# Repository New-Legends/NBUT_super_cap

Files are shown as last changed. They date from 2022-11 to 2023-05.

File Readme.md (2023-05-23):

Image text
# 这是一份由NEW LEGENDS战队开发的10节50法拉电容引爆代码

##  接口介绍:
###      I2C接口
          I2C1: PB7->SDA PB6->SCL             
                连接超级电容充电模块用于检测充电功率
          I2C2: PB11->SDA PB10->SCL
                连接电池用于电池功率检测

###      LED灯接口
          白灯: PB5 输出PWN充电指示灯 pwn
          蓝灯: PA3 超电初始化完成后常亮 闪烁代表初始化失败 ready
          绿灯: PA4 超电放电时绿灯常亮 run
          橙灯: PA5 超电电压大于20v full
          红灯: PA6 电容电压小于12V low

###     充电模块LM5106
          使能: PB3 高电平开启充电 低电平关闭充电
          PWM控制:  PB4控制占空比控制充电电压

###     CAN通讯模块
          CAN_TX -> PB9  CAN_RX -> PB8
          控制板的CAN ID为固定的0x401,此ID固定不出现严重冲突不改！！！
          2023/5/20在这个爱的日子，加入一个新的通讯ID，0x402用于传输功率数据
## 充电接口介绍
            充电使用PWM的占空比控制，占空比越高，则充电功率越大

## 相关数据介绍
            cap_data 用于储存通过can通讯的底盘控制板数据
            cap_ctrl_data 用于储存控制变量

# 
      V1.1 发现问题，控制策略存在问题，尝试与底盘控制板协同控制
            默认升压模块开启，当电容没电时强行降速，直至不超功率运行
            使用该超电板需要将底盘电机的电调的电阻关闭

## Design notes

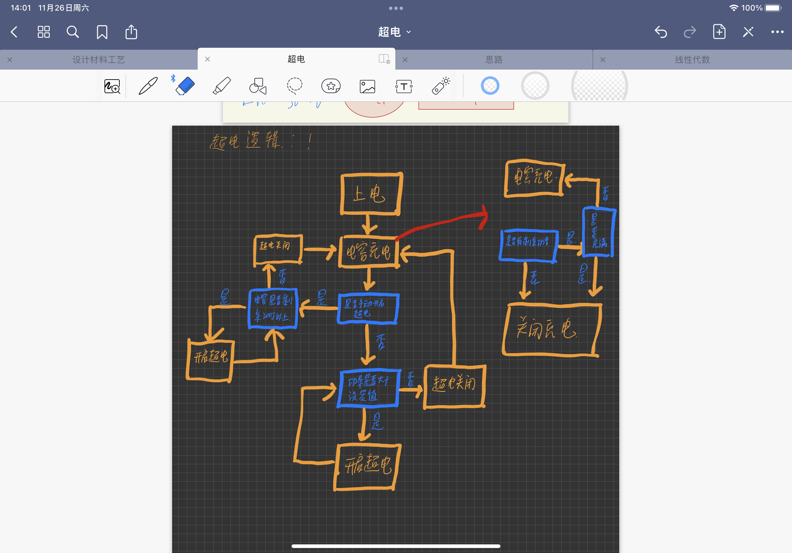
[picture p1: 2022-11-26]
超电运行逻辑图.png

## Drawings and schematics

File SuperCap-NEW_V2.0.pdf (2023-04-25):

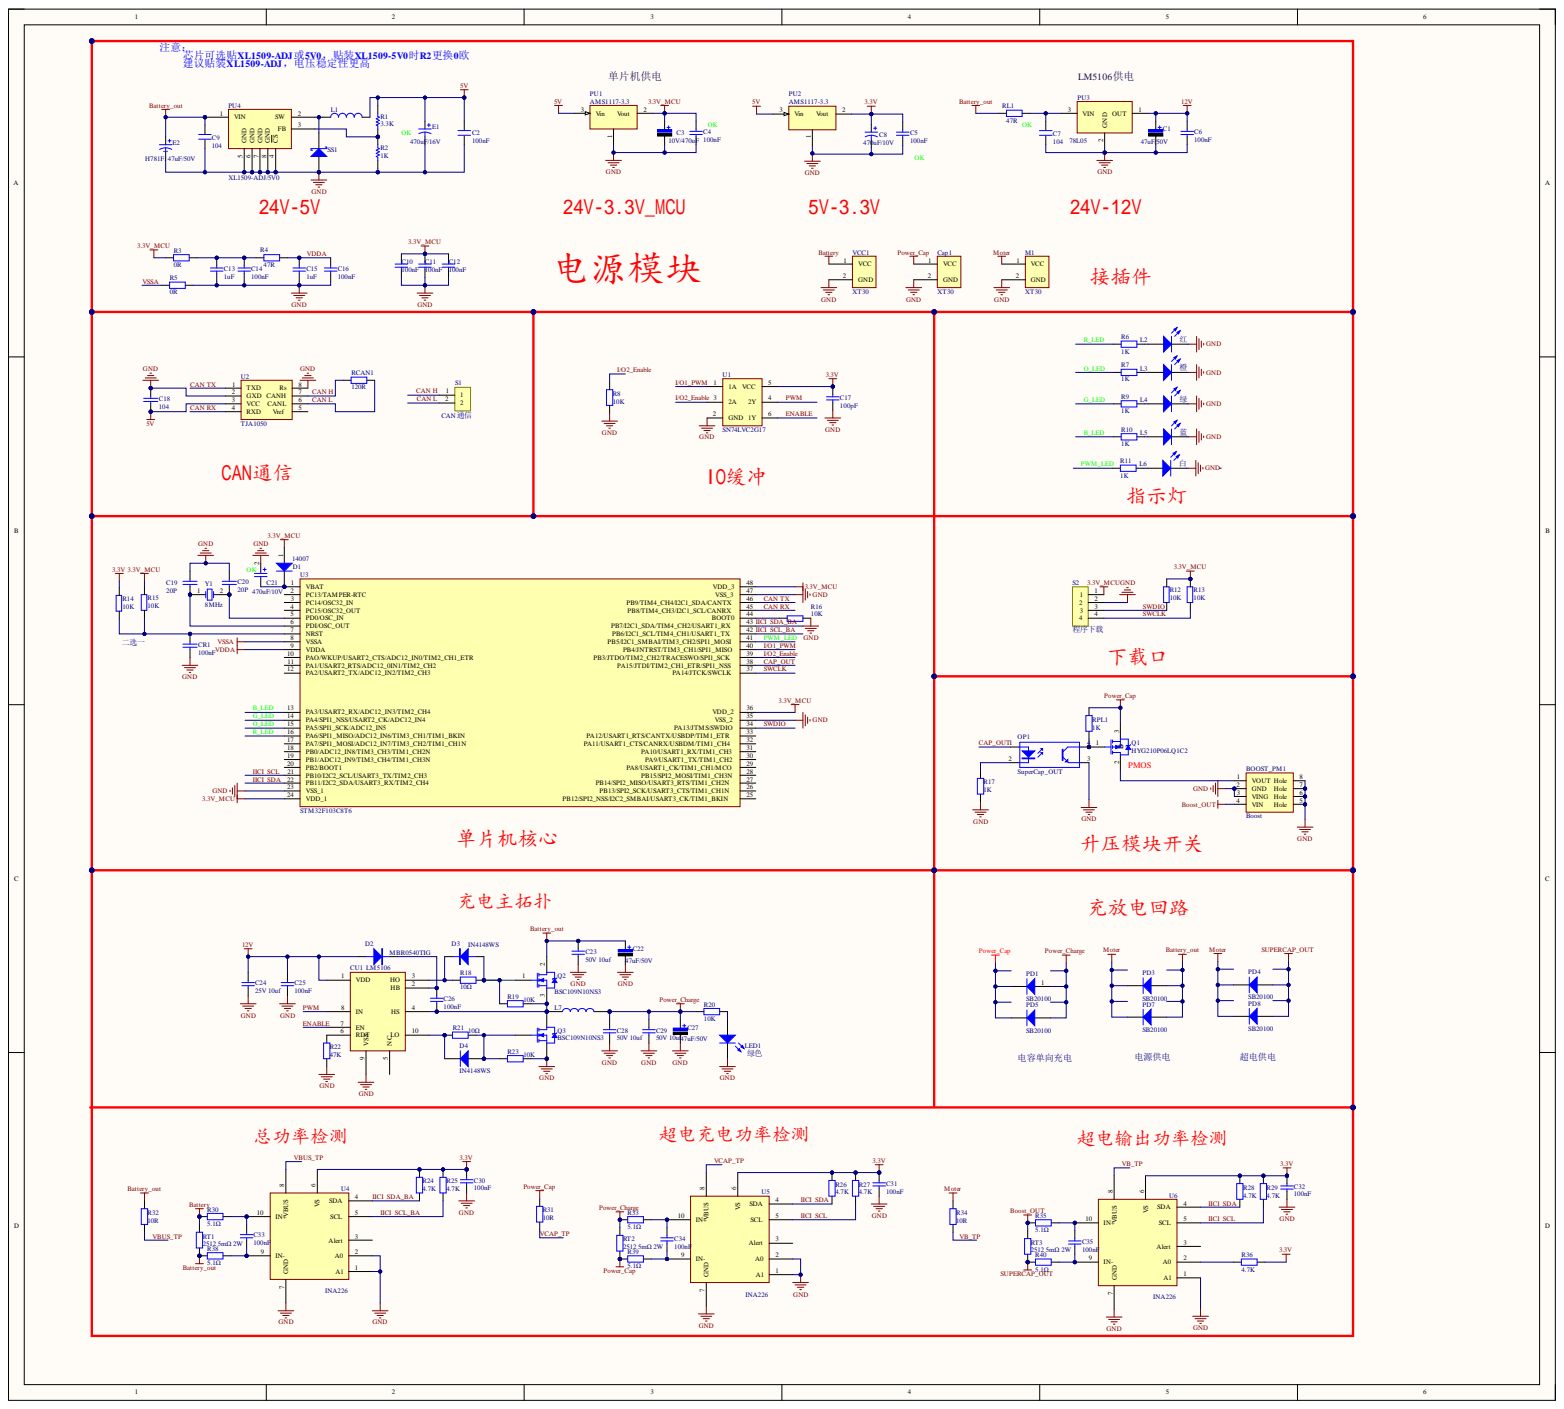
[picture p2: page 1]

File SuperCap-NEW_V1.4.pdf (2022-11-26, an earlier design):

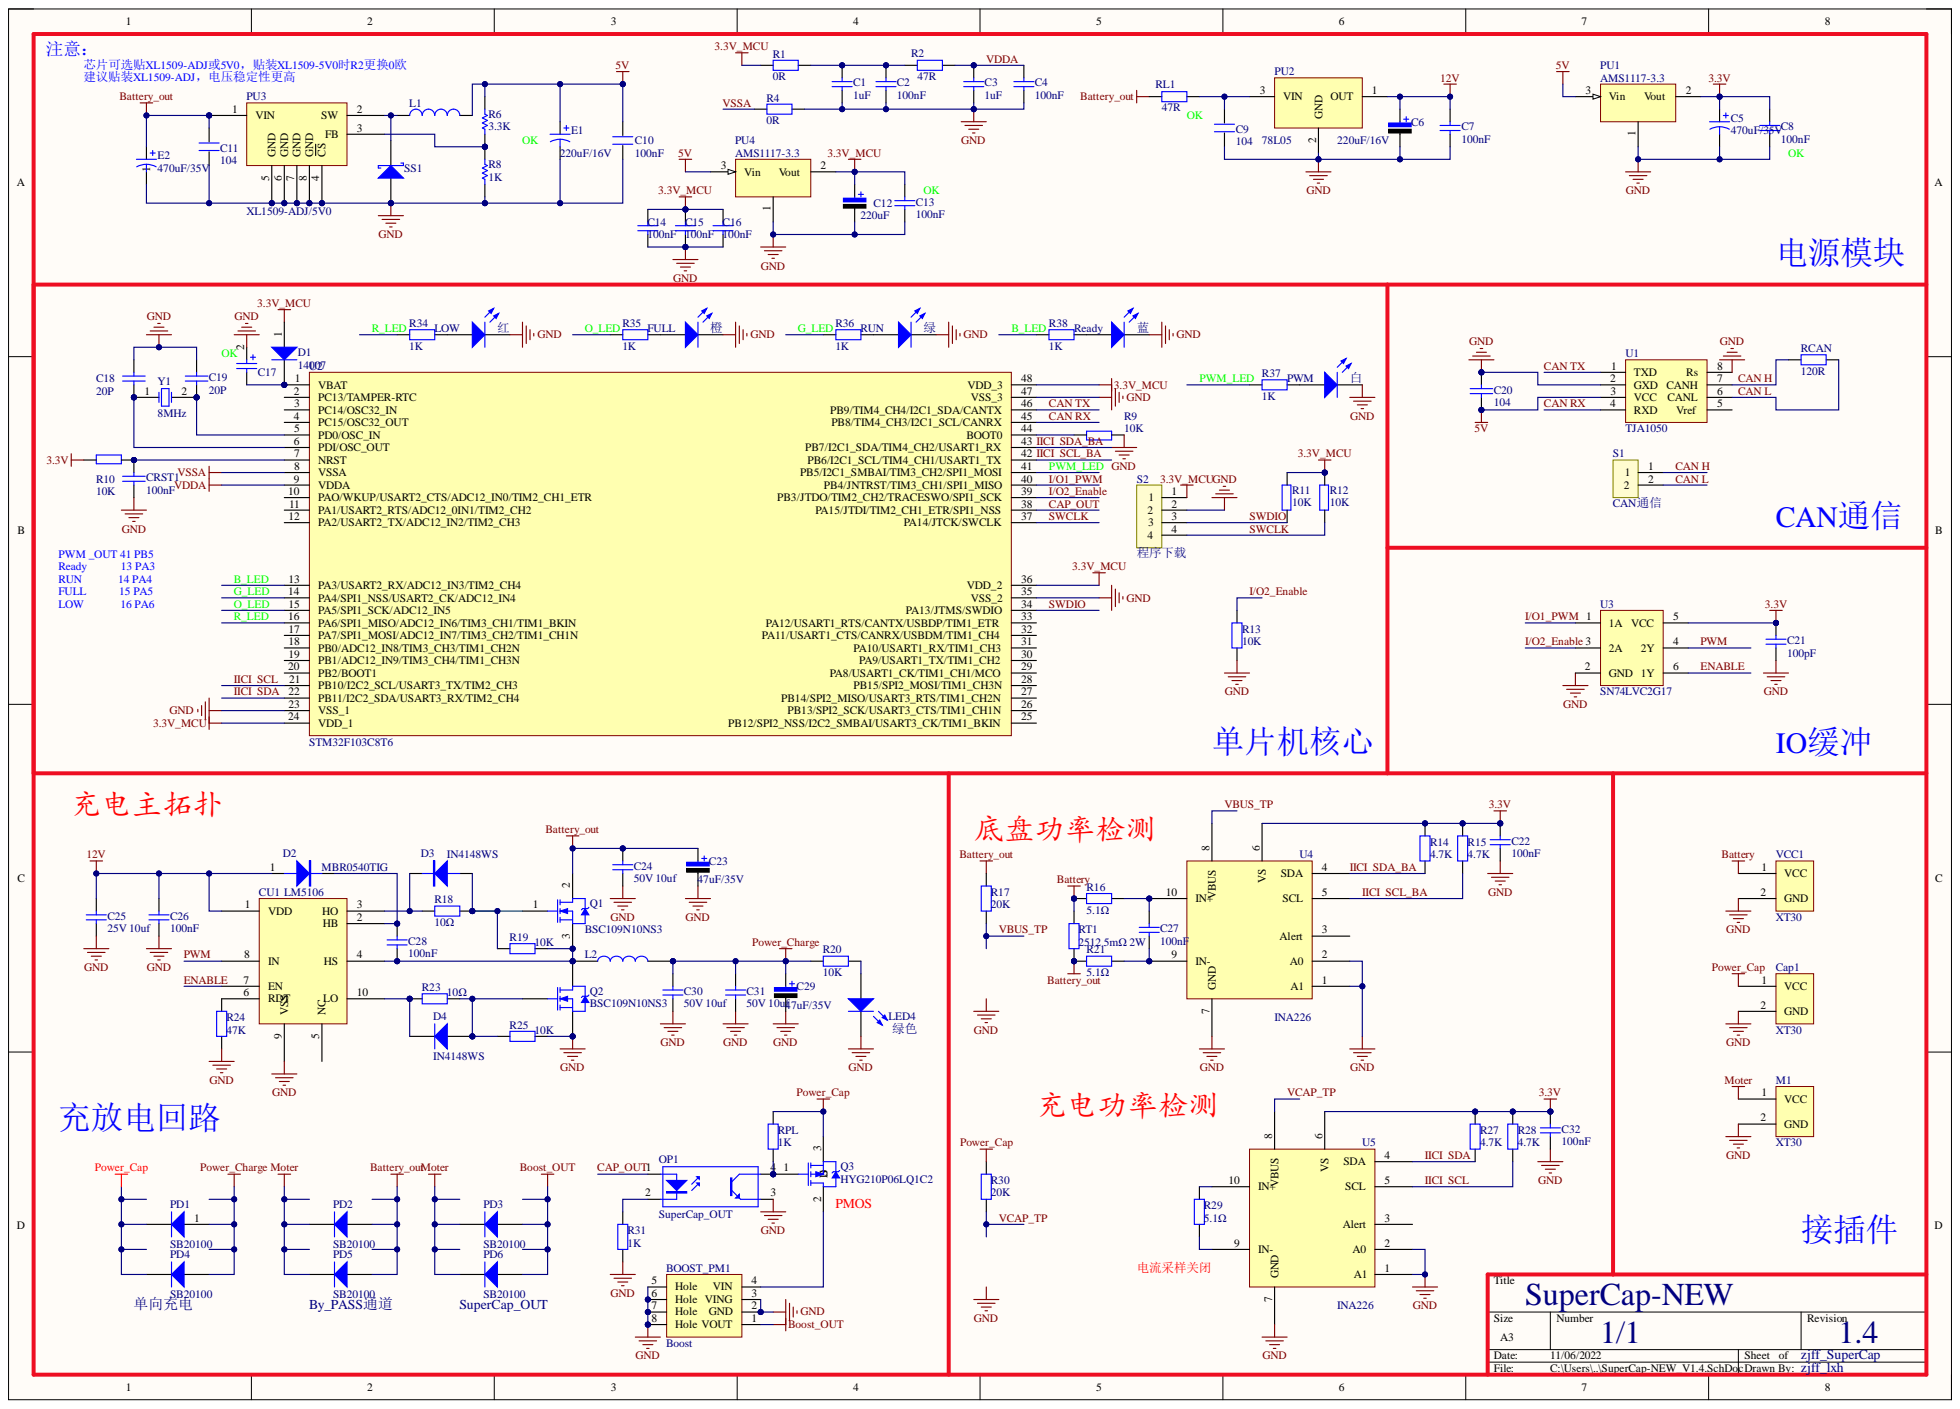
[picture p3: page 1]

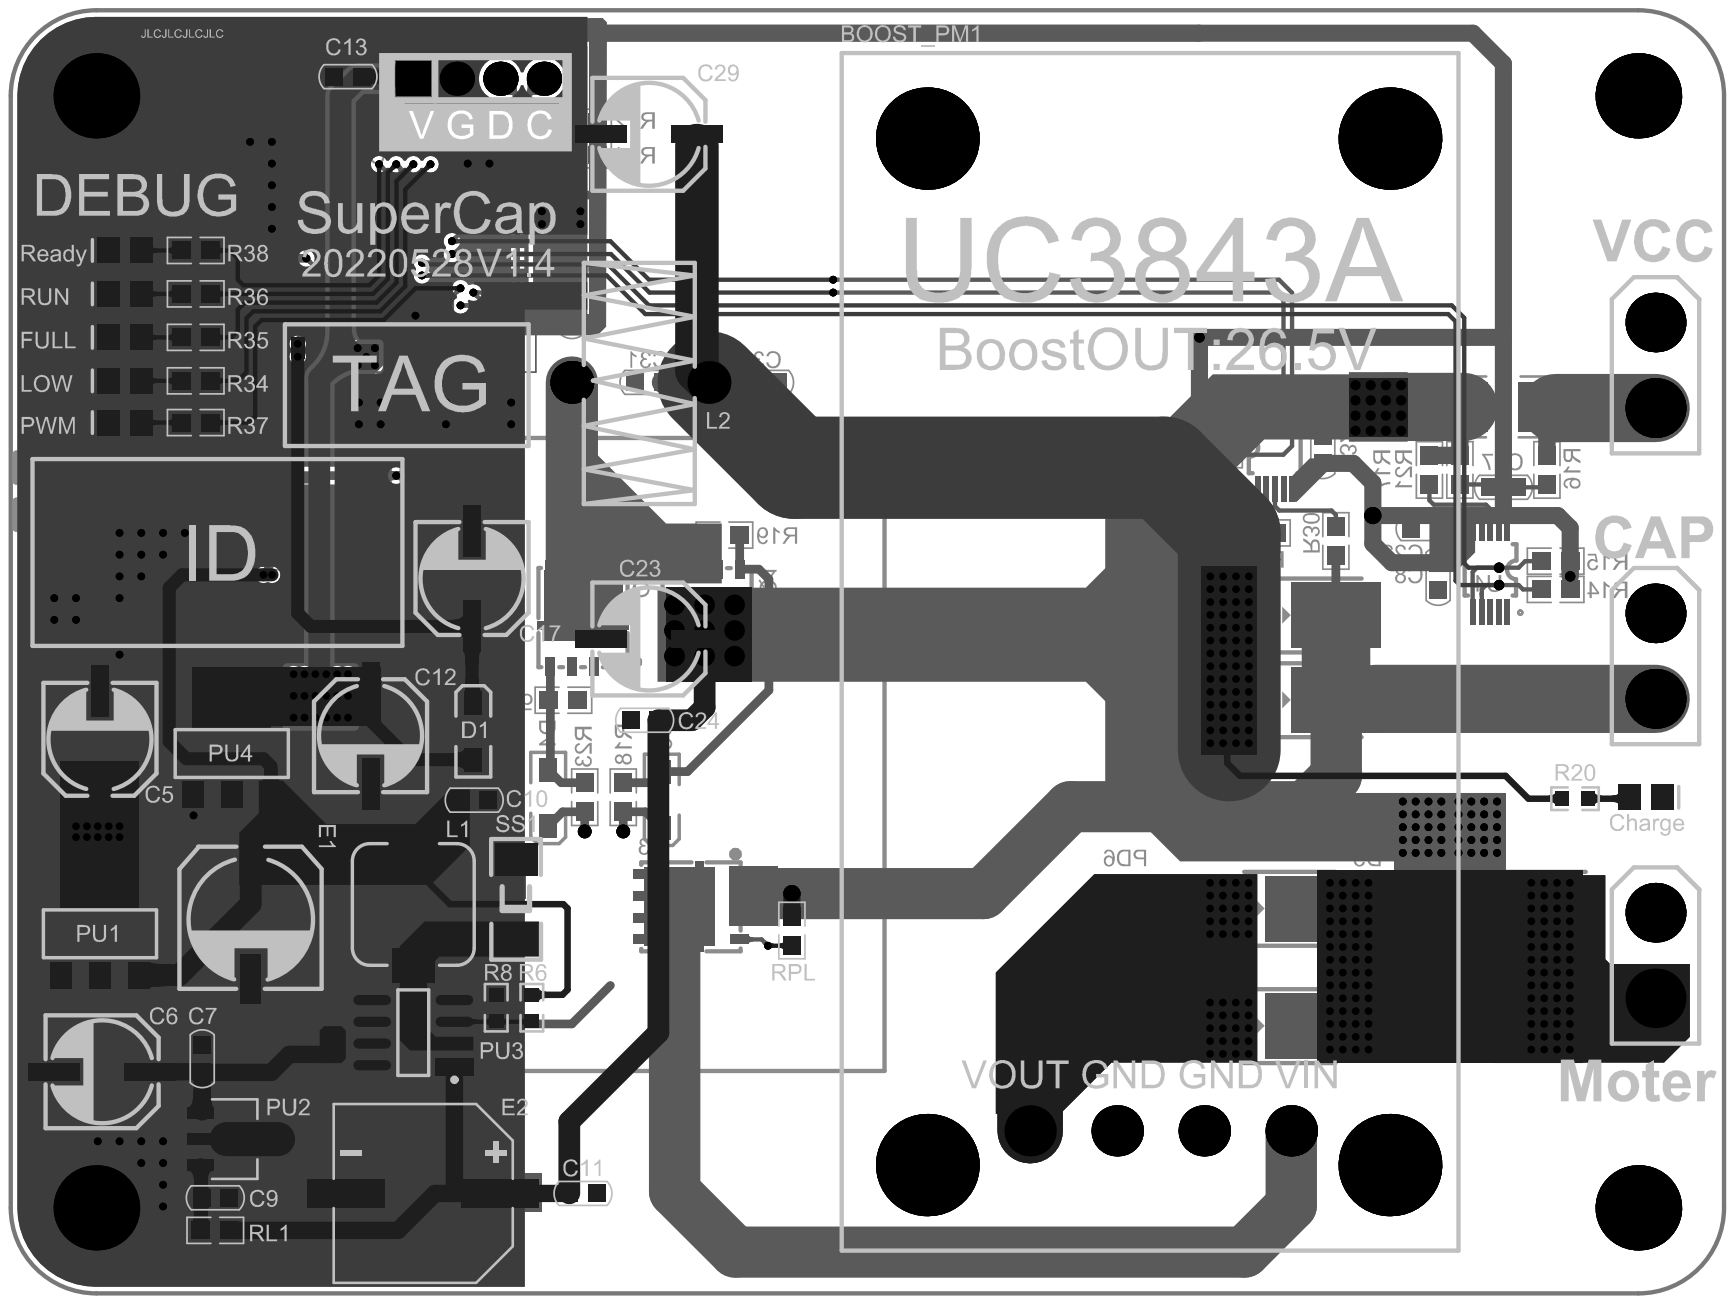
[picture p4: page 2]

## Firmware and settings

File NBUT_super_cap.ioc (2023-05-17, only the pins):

Mcu.UserName=STM32F103C8Tx
PA13.Signal=SYS_JTMS-SWDIO
PA14.Signal=SYS_JTCK-SWCLK
PA15.GPIO_Label=CAP_CTRL
PA15.Signal=GPIO_Output
PA3.GPIO_Label=LED_BLUE
PA3.Signal=GPIO_Output
PA4.GPIO_Label=LED_GREEN
PA4.Signal=GPIO_Output
PA5.GPIO_Label=LED_ORANGE
PA5.Signal=GPIO_Output
PA6.GPIO_Label=LED_RED
PA6.Signal=GPIO_Output
PB10.Signal=I2C2_SCL
PB11.Signal=I2C2_SDA
PB3.GPIO_Label=ENABLE
PB3.Signal=GPIO_Output
PB4.Signal=S_TIM3_CH1
PB6.Signal=I2C1_SCL
PB7.Signal=I2C1_SDA
PB8.Signal=CAN_RX
PB9.Signal=CAN_TX
PD0-OSC_IN.Signal=RCC_OSC_IN
PD1-OSC_OUT.Signal=RCC_OSC_OUT

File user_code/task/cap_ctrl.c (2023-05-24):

/**
 * @file cap_ctrl.c
 * @author NBUT NJY
 * @brief 
 * @version 0.1
 * @date 2022-11-26
 * 
 * @copyright Copyright (c) 2022
 * 
 */
#include "cap_ctrl.h"
#include "pid.h"
#include "task.h"

cap_ctrl_data_t cap_ctrl_data;

void cap_ctrl_task(void const * argument)
{
    Cap_Pid_Init();
    Cap_Ctrl_Init();
while (1)
{
    Cap_Ctrl();
    Power_LED_ctrl();
}
}

/**
 * @brief 返回绝对值
 * 
 * @param a 
 * @return fp32 
 */
fp32 abs(fp32 a)
{
    if(a > 0)
    {
        return a;
    }else
    {
        return -a;
    }
}

/**
 * @brief 超电开始放电
 * 
 */
void Cap_DisCharge_On(void)
{
    Cap_DisCharge_LED_On();
    HAL_GPIO_WritePin(GPIOA,GPIO_PIN_15,GPIO_PIN_SET);
}

/**
 * @brief 超电停止放电
 * 
 */
void Cap_DisCharge_Off(void)
{
    Cap_DisCharge_LED_Off();
    HAL_GPIO_WritePin(GPIOA,GPIO_PIN_15,GPIO_PIN_RESET);
}

/**
 * @brief 电容充电开
 * 
 */
void Cap_Charge_On(void)
{
    Cap_Charge_LED_On();
    HAL_GPIO_WritePin(GPIOB,GPIO_PIN_3,GPIO_PIN_SET);
}

/**
 * @brief 电容充电关
 * 
 */
void Cap_Charge_Off(void)
{
    Cap_Charge_LED_Off();
    HAL_GPIO_WritePin(GPIOB,GPIO_PIN_3,GPIO_PIN_RESET);
}

/**
 * @brief pid初始化
 * 
 */
void Cap_Pid_Init(void)
{
    fp32 cap_pid_parm[6] = {CAP_PID_KP,CAP_PID_KI,CAP_PID_KD,CAP_PID_MAX_IOUT,CAP_PID_MAX_OUT,CAP_PID_MMAX_OUT};
    Pid_Init(PID_SPEED,cap_pid_parm,&INA226_Data_bus.PowerW,&cap_data.power, 0 , &cap_ctrl_data);
    Pid_clear();
}

/**
 * @brief 电容控制初始化
 * 
 */
void Cap_Ctrl_Init(void)
{
    //开启充电
    Cap_Charge_On();
    //开启升压模块
    Cap_DisCharge_On();
    //初始化模式
    cap_ctrl_data.CAP_MODE = CAP_MODE_CHARGE;
    //初始化功率控制
    cap_ctrl_data.duty_cycle = 80;
    //低功率充电
    __HAL_TIM_SetCompare(&htim3,TIM_CHANNEL_1,cap_ctrl_data.duty_cycle);
    HAL_Delay(20000);
    //系统初始化完成
    System_LED_Ready();

    cap_data.power = 80;
}

/**
 * @brief 总控制函数
 * 
 */
void Cap_Ctrl(void)
{
    //获取pid运算结果
    cap_ctrl_data.duty_cycle = Pid_calc(); 
    //控制充电功率
    __HAL_TIM_SetCompare(&htim3,TIM_CHANNEL_1,cap_ctrl_data.duty_cycle);
    //计算电容电量
    cap_ctrl_data.cap_electricity = 0.5*5*INA226_Data_cap.BusV*INA226_Data_cap.BusV;
    //计算抖动电量
    cap_ctrl_data.CAP_SHAKE_DATA = abs(cap_ctrl_data.cap_electricity - cap_ctrl_data.last_cap_electricity);
    //赋值上一次的电量
    cap_ctrl_data.last_cap_electricity = cap_ctrl_data.cap_electricity;
    //计算剩余电源电量百分比
    cap_ctrl_data.residue_electricity = ((INA226_Data_cap.BusV - CAP_LOW_V) / (INA226_Data_bus.BusV - CAP_LOW_V) * 100);
    //输出功率大于210W时关闭升压模块
    // if(INA226_Data_out.PowerW > 210)
    // {
    //     vTaskDelay(3500);
    //     Cap_DisCharge_Off;
    // }

    //手动模式切换
    // if((cap_data.boom == CAP_MODE_USER_DISCHARGE) && (cap_ctrl_data.cap_electricity > CAP_LOW_ELECTRICITY))
    // {
    //     can_cmd_cap_data(INA226_Data_bus.BusV,cap_ctrl_data.cap_electricity,CAP_MODE_USER_DISCHARGE);
    //     //开启放电
    //     Cap_DisCharge_On();
    //     cap_ctrl_data.CAP_MODE = CAP_MODE_USER_DISCHARGE;
    // }

    // else if(cap_ctrl_data.cap_electricity <= CAP_LOW_ELECTRICITY || (cap_data.boom == CAP_MODE_CHARGE && cap_ctrl_data.CAP_MODE == CAP_MODE_USER_DISCHARGE))
    // {
    //     // 如果电容电量过低！
    //     // 关闭放电
    //     Cap_DisCharge_Off();
    //     cap_ctrl_data.CAP_MODE = CAP_MODE_CHARGE;
    // } 

    //自动模式切换
    // if ((cap_ctrl_data.CAP_MODE == CAP_MODE_CHARGE) && (INA226_Data_cap.BusV > INA226_Data_bus.BusV - 1.0))
    // {
    //     //当电容电量足够的时候开启升压模块
    //     //Cap_Charge_Off();
    //     Cap_DisCharge_On();
    //     cap_ctrl_data.CAP_MODE = CAP_MODE_DISCHARGE;
    // } else if((cap_ctrl_data.CAP_MODE == CAP_MODE_DISCHARGE) && (INA226_Data_cap.BusV < 13.0))
    // {
    //     Cap_Charge_On();
    //     //当电容电量低的时候关闭升压模块，同时通过can发送数据使底盘降速
    //     //can_cmd_cap_data(INA226_Data_bus.BusV,cap_ctrl_data.cap_electricity,CAP_MODE_CHARGE);
    //     //Cap_DisCharge_Off();
    //     //cap_ctrl_data.CAP_MODE = CAP_MODE_CHARGE;
    // }
    // else
    // {
    //     Cap_Charge_On();
    //     Cap_DisCharge_On();
    // }

    /*
    //模式切换 当处于充电模式并且电容电量变化小于一定值时判断进入自动超电模式
    if ((cap_ctrl_data.CAP_MODE == CAP_MODE_CHARGE) && (cap_ctrl_data.CAP_SHAKE_DATA < CAP_BAT) && INA226_Data_bus.PowerW > cap_data.power)
    {
        Cap_DisCharge_On();
        cap_ctrl_data.CAP_MODE = CAP_MODE_DISCHARGE;
    } else if((cap_ctrl_data.CAP_MODE == CAP_MODE_DISCHARGE) && (cap_ctrl_data.CAP_SHAKE_DATA < CAP_BAT) && INA226_Data_bus.PowerW < cap_data.power)
    {
        Cap_DisCharge_Off();
        cap_ctrl_data.CAP_MODE = CAP_MODE_CHARGE;
    }
    */
}

void Power_LED_ctrl(void)
{
    if(INA226_Data_cap.BusV > INA226_Data_bus.BusV - 1.0)
    {
        Cap_Electricity_LED_High();
    }else if (INA226_Data_cap.BusV < 12.0)
    {
        Cap_Electricity_LED_Low();
    }else
    {
        Cap_Electricity_LED_Normal();
    }
}

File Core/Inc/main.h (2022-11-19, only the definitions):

#define LED_BLUE_Pin GPIO_PIN_3
#define LED_BLUE_GPIO_Port GPIOA
#define LED_GREEN_Pin GPIO_PIN_4
#define LED_GREEN_GPIO_Port GPIOA
#define LED_ORANGE_Pin GPIO_PIN_5
#define LED_ORANGE_GPIO_Port GPIOA
#define LED_RED_Pin GPIO_PIN_6
#define LED_RED_GPIO_Port GPIOA
#define CAP_CTRL_Pin GPIO_PIN_15
#define CAP_CTRL_GPIO_Port GPIOA
#define ENABLE_Pin GPIO_PIN_3
#define ENABLE_GPIO_Port GPIOB

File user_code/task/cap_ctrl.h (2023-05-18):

/**
 * @file cap_ctrl.h
 * @author NBUT NJY
 * @brief
 * @version 0.1
 * @date 2022-11-26
 *
 * @copyright Copyright (c) 2022
 *
 */
#ifndef CAP_CTRL_H
#define CAP_CTRL_H

#include "main.h"
#include "FreeRTOS.h"
#include "tim.h"
#include "bsp_led.h"
#include "bsp_ina226.h"
#include "can_receive.h"
#include "struct_typedef.h"

//充电pid
#define CAP_PID_KP 0.01f
#define CAP_PID_KI 0.0f
#define CAP_PID_KD 0.0f
#define CAP_PID_MAX_IOUT 200.0f
#define CAP_PID_MAX_OUT 980.0f
#define CAP_PID_MMAX_OUT 980.0f

//参数设置
#define CAP_SHAKE 10.0f //抖动电量
#define CAP_LOW_ELECTRICITY 400.0f //电容低电量
#define CAP_BAT 0.2f //电容满电电压与电池电压差
#define CAP_LOW_V 11.0f //电容最低电压

//模式切换
#define CAP_MODE_CHARGE 0          //充电模式
#define CAP_MODE_DISCHARGE 1       //自动超电模式
#define CAP_MODE_USER_DISCHARGE 2  //手动超电模式

//控制数据结构体
typedef struct 
{
    fp32 duty_cycle; //充电占空比
    float cap_electricity; // 电容电量
    fp32 last_cap_electricity; //上一次电容容量
    fp32 CAP_SHAKE_DATA;       //电容电量抖动
    uint8_t CAP_MODE;      //电容模式
    float residue_electricity;//超电剩余电量百分比
}cap_ctrl_data_t;

extern cap_ctrl_data_t cap_ctrl_data;

void Cap_DisCharge_On(void);
void Cap_DisCharge_Off(void);

void Cap_Pid_Init(void);
void Cap_Ctrl_Init(void);
void Cap_Ctrl(void);

void Power_LED_ctrl(void);
#endif

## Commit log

2022-11-24 i2c通讯完成
    充电控制
2022-11-26 电池电压功率解算完成
    1
    [SuperCap-NEW_V1.4.PcbDoc]
2022-11-26 led完成
    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
2022-11-27 can通讯完成
    pid算法
2022-11-29 PID算法完成
    6
2022-11-29 新的readme
2022-11-30 充放电解算
2022-11-30 主控制完成一半
2022-12-01 完成，还需要测试
    进行测试
2022-12-01 完成，需要测试
    测试
2022-12-06 功率控制
2023-01-06 pid调整
    pid调整
2023-01-15 船新的控制逻辑
2023-01-15 can通讯测试完成
2023-01-15 can通讯调整
2023-01-17 can通讯
2023-04-25 更新了超电输出数据获取
2023-04-27 联盟赛
    联盟赛
    [SuperCap-NEW-V2.0.PcbDoc, SuperCap-NEW_V2.0.PrjPcb, SuperCap-NEW_V2.0.SchDoc]
2023-05-11 测试摔好版
2023-05-17 通讯1.0（未完成版）
2023-05-17 通讯1.1（未完成）
2023-05-20 新增通讯ID 0x402 用于功率
2023-05-23 输出功率超过210W，3.5秒后关闭升压模块，测试版
2023-05-23 双通讯完整版
    [SuperCap-NEW_V2.1.2.PcbDoc, SuperCap-NEW_V2.1.2.PrjPcb, SuperCap-NEW_V2.1.2.SchDoc]
2023-05-23 Revert "输出功率超过210W，3.5秒后关闭升压模块，测试版"
    This reverts commit 84fd01f26a9d9ea42f9d163e7aec2ba0b3dc6f16.
    [bsp_ina226.c, cap_ctrl.c]
2023-05-23 Revert "新增通讯ID 0x402 用于功率"
    This reverts commit 79dee263ad2fb10f951cf2abf070bddbe9a14d83.
    [bsp_ina226.c, bsp_ina226.h, cap_ctrl.c]
2023-05-23 完整通讯
2023-05-24 超电充电功率检测
2023-05-27 稳定离线版
    SLW拉稀了都是离线的

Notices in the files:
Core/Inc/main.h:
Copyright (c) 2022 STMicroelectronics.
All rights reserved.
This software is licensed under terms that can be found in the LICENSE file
